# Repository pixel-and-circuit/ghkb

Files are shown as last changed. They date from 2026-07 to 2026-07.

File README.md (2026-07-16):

GHKB

<picture>
  <source media="(prefers-color-scheme: dark)" srcset="docs/images/case-preview-dark.png">
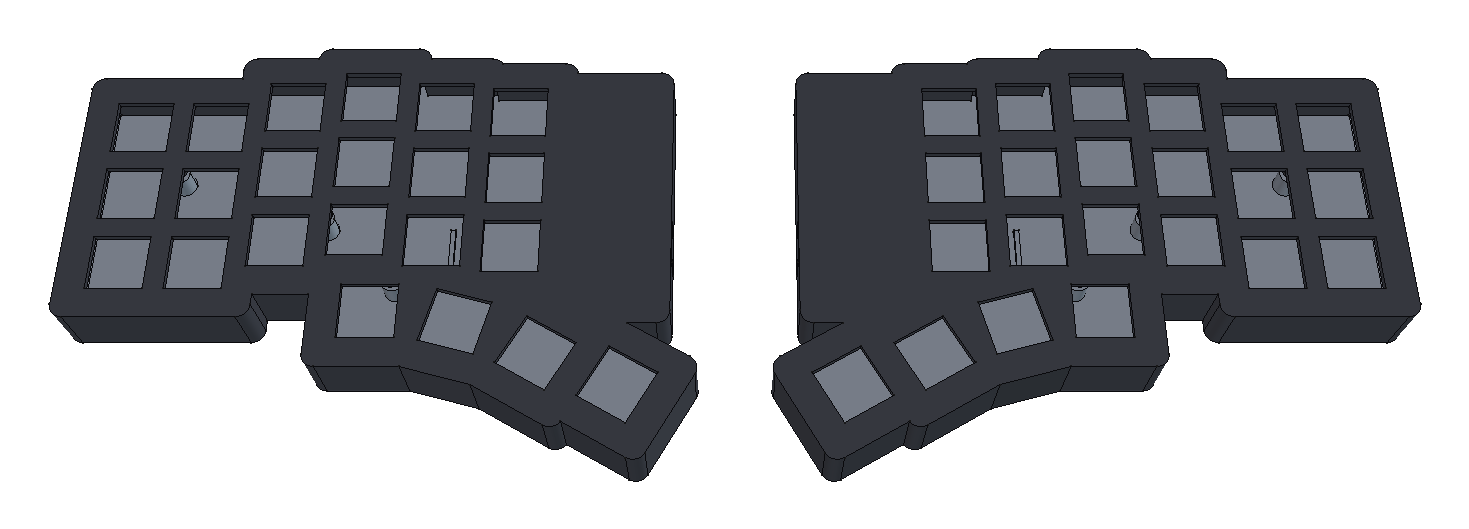
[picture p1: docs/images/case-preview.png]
GHKB split keyboard case, FreeCAD preview render of both halves
  
</picture>

GHKB is an open-source split mechanical keyboard project focused on custom hardware, modern firmware, and long-term experimentation.

The goal of this project is to build a fully custom wireless split keyboard from the ground up, including both the hardware and firmware stack. Rather than assembling an existing design, GHKB documents the complete engineering process—from PCB and enclosure design to firmware development.

Goals

Phase 1: Build a Reliable Daily Driver

Develop a fully functional wireless split keyboard featuring:

* Custom PCB designed with KiCad (single reversible design shared by both halves)
* Custom 3D-printed enclosure
* MX-compatible mechanical switches on hotswap sockets
* Battery-powered operation
* Bluetooth Low Energy (BLE)
* ZMK firmware
* Comfortable ergonomic layout

Controller strategy: the first prototype targets an off-the-shelf nRF52840
controller module (e.g. Nice!Nano) socketed onto the PCB. Designing a fully
custom controller—placing the nRF52840 QFN/BGA package directly on the board—is
a later, optional goal once the socketed design is validated.

Hardware design decisions:

* Layout: 42 keys — a 3x6 column-staggered matrix plus a 3-key thumb cluster
  per half (Corne-style), with an optional EC11 rotary encoder position.
* PCB: one reversible PCB serves both halves (components mount on the front
  for one half and on the back for the other), halving design and
  manufacturing effort.
* Switches: MX hotswap sockets (Kailh), so the prototype can be reworked
  without desoldering.
* Display: none. A display only shows status (battery, layer, BLE profile)
  and is not needed for keyboard operation; omitting it saves cost, battery,
  and three GPIOs kept as spares.
* RGB: deferred past Phase 1. Per-key RGB is battery-hostile on a wireless
  board; at most, unpopulated footprints are reserved.
* Layout generation: switch placement and the board outline are generated
  with ergogen and imported into KiCad, so layout iterations stay
  reproducible.

Phase 2: Develop a TinyGo Firmware

Create a native TinyGo firmware targeting the same hardware platform. The
long-term objective is not simply to recreate existing keyboard firmware, but to
explore whether a modern Go-based embedded ecosystem can become a practical
alternative for custom keyboard development.

Because the wireless BLE stack is by far the highest-risk part of this effort,
Phase 2 is split into two independent milestones:

Phase 2a: USB-wired TinyGo firmware (high feasibility)

Bring up a wired, single-board or wired-split TinyGo build using USB HID, which
is well supported in the TinyGo ecosystem and has existing precedent. This
establishes the matrix scanning, keymap, and feature layer in Go without
depending on wireless.

Phase 2b: BLE-wireless TinyGo firmware (research / uncertain)

Extend the firmware to full wireless operation. This is genuinely exploratory
and may not be achievable: TinyGo's BLE support (`tinygo.org/x/bluetooth`) has
historically centered on the central/scanner role and relies on Nordic's
SoftDevice, whereas a keyboard needs a BLE peripheral with HID-over-GATT,
pairing/bonding, and a wireless split link. ZMK gets these for free from
Zephyr's mature BLE stack; in TinyGo much of it would have to be built from
scratch. Treat Phase 2b as an open question, not a scheduled deliverable.

Planned Features

* Wireless split architecture
* Bluetooth Low Energy (BLE)
* Multi-device pairing
* Battery management
* USB-C charging
* Layer support
* Mod-Tap / Hold-Tap
* Combo keys
* Rotary encoder support
* Optional RGB lighting (post-Phase 1)
* Firmware updates via bootloader

Repository Structure

Note: this is the planned/target layout for the completed project. The
repository currently contains only this README while the project is in the
planning and hardware design phase; directories below are created as work
progresses.

```
.
├── README.md
├── HARDWARE.md
├── LICENSE
├── .gitignore
├── config/
│   ├── west.yml
│   ├── ghkb.keymap
│   └── boards/shields/ghkb/
├── build.yaml
├── firmware/
│   └── tinygo/
├── pcb/
│   ├── ergogen/
│   │   ├── config.yaml
│   │   └── footprints/
│   ├── keyboard.kicad_pro
│   ├── keyboard.kicad_sch
│   ├── keyboard.kicad_pcb
│   └── libraries/
├── case/
│   ├── source/
│   │   ├── params.py
│   │   ├── layout.py
│   │   ├── ghkb_case.py
│   │   ├── render_preview.py
│   │   ├── left.FCStd
│   │   └── right.FCStd
│   ├── exports/
│   │   ├── left.step / right.step
│   │   └── {left,right}_{top,bottom}.stl
│   └── reference/
│       └── keyboard_pcba.step
├── docs/
│   ├── assembly.md
│   ├── wiring.md
│   └── images/
│       └── case-preview{,-dark}.png
└── bom/
    └── bom.csv
```

Directory Overview

Directory	Description
HARDWARE.md	Sourcing guide: full parts table with purchase links, PCB fab options, and assembly cautions.
config	Production ZMK firmware config (west manifest, keymap, custom ghkb shield). Lives at the repo root because ZMK's reusable CI workflow expects config_path/build_matrix_path relative to the west topdir, which must be the repo root - not a nested subdirectory.
firmware/tinygo	Experimental TinyGo firmware implementation.
pcb	KiCad project files, schematics, PCB layout, and custom libraries.
pcb/ergogen	Ergogen layout source (YAML) and reversible footprint library.
case/source	Parametric enclosure build scripts (params/layout/ghkb_case.py) and the generated FreeCAD documents. The switch plate is integrated into the top shell, so there is no separate plate design. Rebuild everything with `freecadcmd case/source/ghkb_case.py`; the build asserts its geometry against the routed PCB and aborts on drift. `render_preview.py` regenerates the README preview images from the built FCStd documents (needs the FreeCAD GUI).
case/exports	Exported manufacturing files (per-half STEP, print-ready top/bottom STLs).
case/reference	kicad-cli STEP export of the routed PCB, used for interference checks.
docs	Assembly guide, wiring documentation, and project images.
bom	Bill of Materials used to build the keyboard.

Roadmap

* Finalize the keyboard layout (42-key, 3x6+3 per half)
* Design the PCB (single reversible board, ergogen + KiCad)
* Design the enclosure (integrated-plate top shell + screwed lid, parametric FreeCAD build; v1 done, pending print validation)
* Build the first prototype
* Bring up ZMK firmware
* Validate the hardware
* Use as a daily driver
* Develop USB-wired TinyGo firmware (Phase 2a)
* Investigate BLE-wireless TinyGo firmware (Phase 2b, research)
* Document the complete development process

Status

This project is currently in the planning and hardware design phase.

Contributing

Contributions are welcome.

Whether you are interested in mechanical keyboards, embedded systems, TinyGo, ZMK, PCB design, or 3D modeling, feel free to open an issue or submit a pull request.

License

This project is dual-licensed to ensure that anyone who uses, modifies, or sells
GHKB — commercially or otherwise — must release their own source under the same
copyleft terms.

- **Software / firmware / source code** (everything in `config/`, `zmk/`,
  `modules/`, `firmware/`, build scripts, documentation sources, etc.) is
  licensed under the **GNU General Public License v3.0 (GPL-3.0)** — a strong
  copyleft license. You may sell copies, but any distributed modified version
  must be released as source under GPL-3.0. See the `LICENSE` file.

- **Hardware designs** (`pcb/`, `case/`, including KiCad projects, schematics,
  PCB layouts, footprints, and 3D-printed enclosure source) are licensed under
  the **CERN Open Hardware Licence v2 – Strongly Reciprocal (CERN-OHL-S)**.
  Any product or design derived from these must have its corresponding design
  source made available under the same licence. See the `LICENSE-HARDWARE` file.

In short: **commercial sale is allowed, but reciprocity is mandatory** — if you
convey GHKB (or a derivative) to others, your modified software and hardware
source must stay open under these licenses.

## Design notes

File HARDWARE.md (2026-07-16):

# GHKB Hardware Sourcing

> **License note:** the hardware designs in this repository (`pcb/`, `case/`,
> KiCad projects, schematics, PCB layouts, footprints, and the 3D-printed
> enclosure source) are licensed under the **CERN Open Hardware Licence v2 –
> Strongly Reciprocal (CERN-OHL-S)**. You may manufacture and sell hardware
> based on these designs, but any product or derived design you convey to others
> must have its corresponding design source made available under CERN-OHL-S.
> See `LICENSE-HARDWARE`. (Software/firmware is separately licensed under
> GPL-3.0 — see `LICENSE`.)

조달용 부품 목록. 기준: `pcb/keyboard.kicad_pcb`(리버서블 1종)과
`case/source/params.py`의 v1 설계. 수량은 **양쪽 하프 합산 기준**이며,
소모품(다이오드/소켓/나사)은 여유분을 포함해 사는 것을 전제로 팩 단위
링크를 걸었다. 링크와 가격은 2026-07 조회 기준이라 품절 시 동일 검색어로
대체하면 된다.

부품별 정확한 대응 규격의 근거는 `pcb/ergogen/footprints/*.js` 헤더에
문서화되어 있다 (ceoloide 풋프린트가 명시하는 호환 부품).

## PCB 주문

| 항목 | 값 |
|---|---|
| 보드 | `pcb/keyboard.kicad_pcb` — 리버서블 1종, 좌/우 공용 |
| 외형 | 149.2 × 105.8 mm |
| 층수 / 두께 | 2층 / 1.6 mm |
| 표면처리 | HASL(무연)이면 충분, ENIG 선택사항 |
| 수량 | 2장 사용 (대부분 업체 최소 5장 — 여분은 자연 확보) |
| 특이사항 | M2.2 NPTH 6개 포함. `PWR1`(전원 스위치) 패드가 보드 엣지에 걸리는 것은 사이드 마운트 부품의 의도된 배치 (무넷 기계 패드) |

거버/드릴 파일은 발주 직전 `kicad-cli`로 생성한다 (업체별 프리셋 상이).

### 발주 서비스

| 서비스 | 비고 |
|---|---|
| [JLCPCB](https://jlcpcb.com/) | 해외(중국). 개인 개발자 사실상 표준 — 2층 5장 $2~ 수준, 한국 배송 1~2주. KiCad 거버 그대로 접수 |
| [PCBWay](https://www.pcbway.com/) | 해외(중국). JLCPCB와 양대 산맥, 품질/옵션 다양 |
| [한샘디지텍](https://www.hsdgt.com/) | 국내. 소량 시제작 대표 업체 — 빠른 납기, 한국어 응대 (해외 대비 가격 높음) |
| [샘플PCB](https://www.samplepcb.co.kr/) | 국내. 온라인 견적/발주 플랫폼 |

## 보드 실장 부품

| 부품 | 규격 / 부품번호 | 필요 수량 (구매 단위) | 링크 |
|---|---|---|---|
| 컨트롤러 | nice!nano v2 호환 (SuperMini nRF52840) | 2 | [AliExpress](https://www.aliexpress.com/item/1005009026511947.html) |
| 컨트롤러 소켓 (암) | 2.54mm 라운드홀 female 헤더, 12P×4줄 (40P 바 재단) | 4줄 (10줄 팩) | [AliExpress](https://www.aliexpress.com/item/32896689725.html) |
| 컨트롤러 핀 (수) | 2.54mm 금도금 라운드 수핀, 24핀/보드 | 48핀 (40P×10줄 팩) | [AliExpress](https://www.aliexpress.com/item/32219458766.html) |
| 핫스왑 소켓 | Kailh CPG151101S11 (MX) | 42 (70개 팩) | [AliExpress](https://www.aliexpress.com/item/1005012011087592.html) |
| 다이오드 | 1N4148, DO-35 THT (SOD-123 겸용 풋프린트) | 44 (50개 팩) | [AliExpress](https://www.aliexpress.com/item/1005007970187200.html) |
| 배터리 커넥터 | JST S2B-PH-K-S (PH 2.0mm, THT 사이드) | 2 (10개 팩) | [AliExpress](https://www.aliexpress.com/item/1005007176267255.html) |
| 배터리 | LiPo 301230, 3.7V ~110mAh, PH2.0 플러그, 보호회로 포함 | 2 | [AliExpress](https://www.aliexpress.com/item/1005005348368664.html) |
| 전원 스위치 | MSK-12C02 7핀 SMD 슬라이드 (Alps SSSS811101 호환) | 2 (50개 팩) | [AliExpress](https://www.aliexpress.com/item/4000685483225.html) |
| 리셋 스위치 | C&K PTS636 SM43 LFS (THT 상면 누름) | 2 (최소 5개) | [LCSC C2689636](https://www.lcsc.com/product-detail/C2689636.html) — 알리 미취급 |
| 로터리 엔코더 (옵션) | EC11, 푸시버튼 포함, 샤프트 15mm 권장 | 0~2 (5개 팩) | [AliExpress](https://www.aliexpress.com/item/1005008708996963.html) |

## 스위치 / 키캡

| 부품 | 규격 | 필요 수량 | 링크 |
|---|---|---|---|
| 키 스위치 | MX 호환 (예: Gateron Milky Yellow Pro, 5핀) | 42 (45개 팩) | [AliExpress](https://www.aliexpress.com/item/1005009861228283.html) |
| 키캡 | 1u × 42 (XDA/DSA blank PBT, Corne류 세트) | 1세트 | [AliExpress](https://www.aliexpress.com/item/1005008944545863.html) |
| 엔코더 노브 (옵션) | 6mm D/널링 샤프트용, 외경 ≤19mm | 0~2 | EC11 구매 시 함께 검색 |

## 케이스 하드웨어

케이스 자체는 구매가 아니라 출력: `case/exports/{left,right}_{top,bottom}.stl`
(PETG/PLA, 페리미터 4+, 인필 40%+, 쉘은 플레이트면·리드는 바깥면을 베드에).

| 부품 | 규격 | 필요 수량 (구매 단위) | 링크 |
|---|---|---|---|
| 히트셋 인서트 | M2, OD 3.2 × L 4.0 (구매 시 이 치수 선택 필수) | 10 (키트) | [AliExpress](https://www.aliexpress.com/item/1005007830491580.html) |
| 케이스 나사 | M2×14 접시머리 (DIN 965, 90°) | 10 (100개 팩) | [AliExpress](https://www.aliexpress.com/item/32367579698.html) |
| 범폰 | Ø8 × 2mm 실리콘, 자체접착 | ~12 (팩) | [AliExpress](https://www.aliexpress.com/item/1005006455782191.html) |

## 기타

- USB-C **데이터** 케이블 1개 (펌웨어 플래싱/충전용, 충전전용 케이블 불가)
- 납땜 인두 + 인서트 압입 팁 (인서트 키트에 팁 포함 옵션 있음)

## 조립 시 주의

- **TRRS 커넥터는 없다.** 완전 무선(BLE) 스플릿이라 보드에 풋프린트
  자체가 없다 — 유선 스플릿 BOM을 참고해 사지 말 것.
- **LiPo 극성**: JST-PH 배터리의 +/− 배선은 표준화되어 있지 않다.
  연결 전 보드 실크의 +/− 표기와 대조하고, 반대면 커넥터에서 핀을
  빼서 바꿔 끼운다. 극성 반대로 꽂으면 컨트롤러가 죽는다.
- **리버서블 보드**: 같은 PCB 2장에서 오른쪽은 앞면(F, "R hand back
  side" 실크 기준), 왼쪽은 뒷면(B)에 부품을 실장한다. 하프당 실장면이
  다를 뿐 부품은 동일.
- 컨트롤러는 직납하지 않고 소켓 실장한다 (라운드홀 암 헤더를 PCB에,
  수핀을 나노에). 클론 보드에 동봉되는 사각핀 헤더는 라운드 소켓과
  마모 궁합이 나빠 쓰지 않는다.

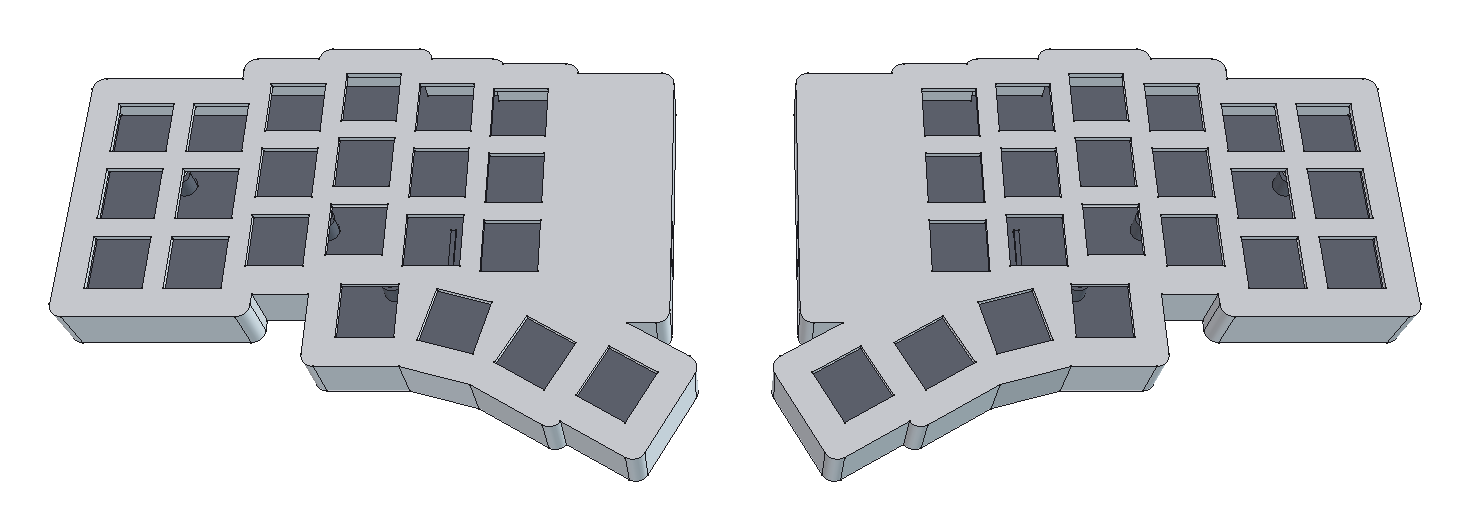
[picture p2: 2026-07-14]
docs/images/case-preview-dark.png

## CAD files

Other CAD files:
case/exports/left.step
case/reference/keyboard_pcba.step
case/exports/right_bottom.stl
case/exports/right_top.stl
case/exports/right.step
case/exports/left_top.stl
case/exports/left_bottom.stl
case/source/left.FCStd
case/source/right.FCStd

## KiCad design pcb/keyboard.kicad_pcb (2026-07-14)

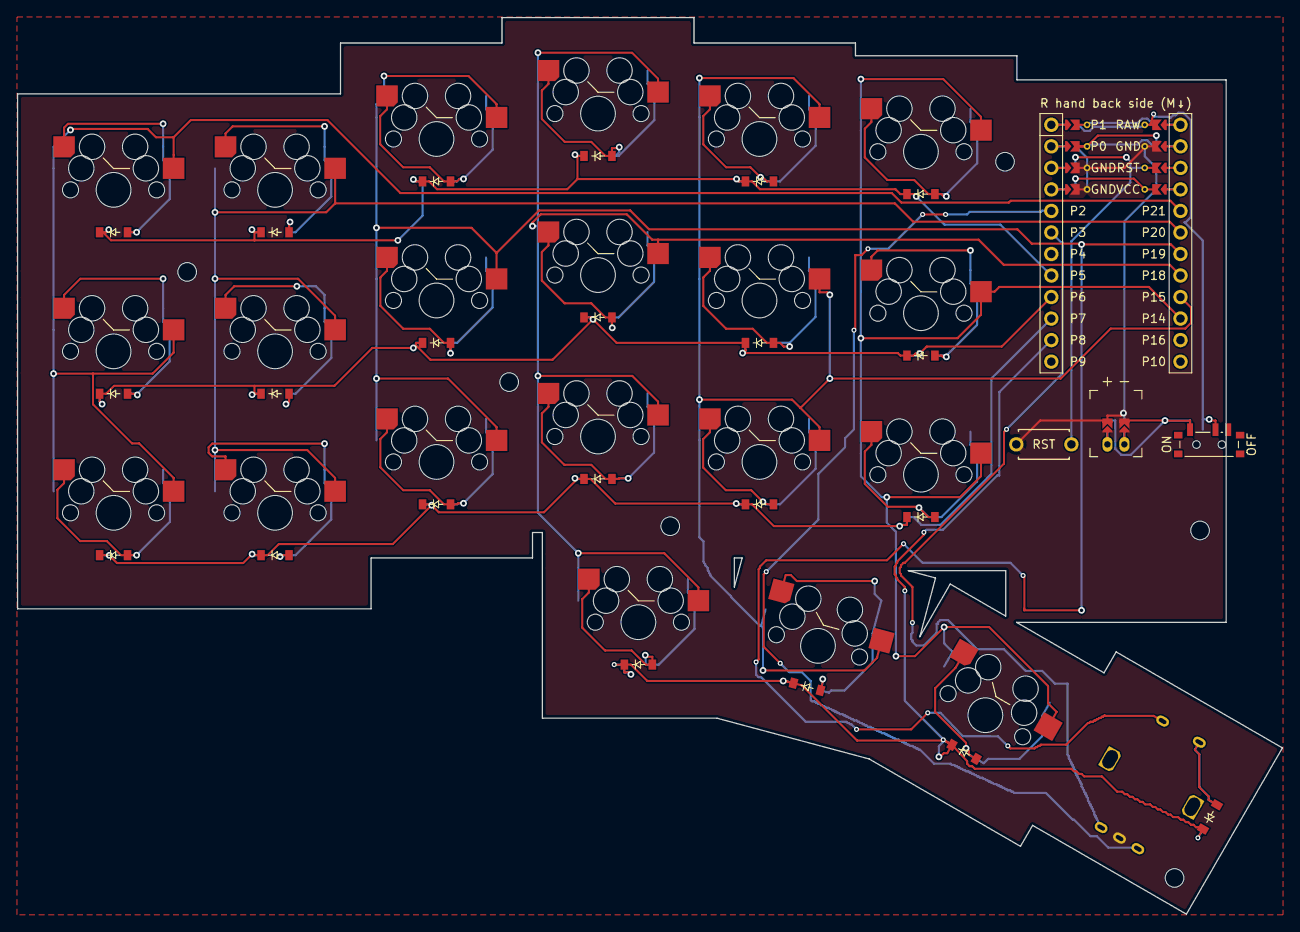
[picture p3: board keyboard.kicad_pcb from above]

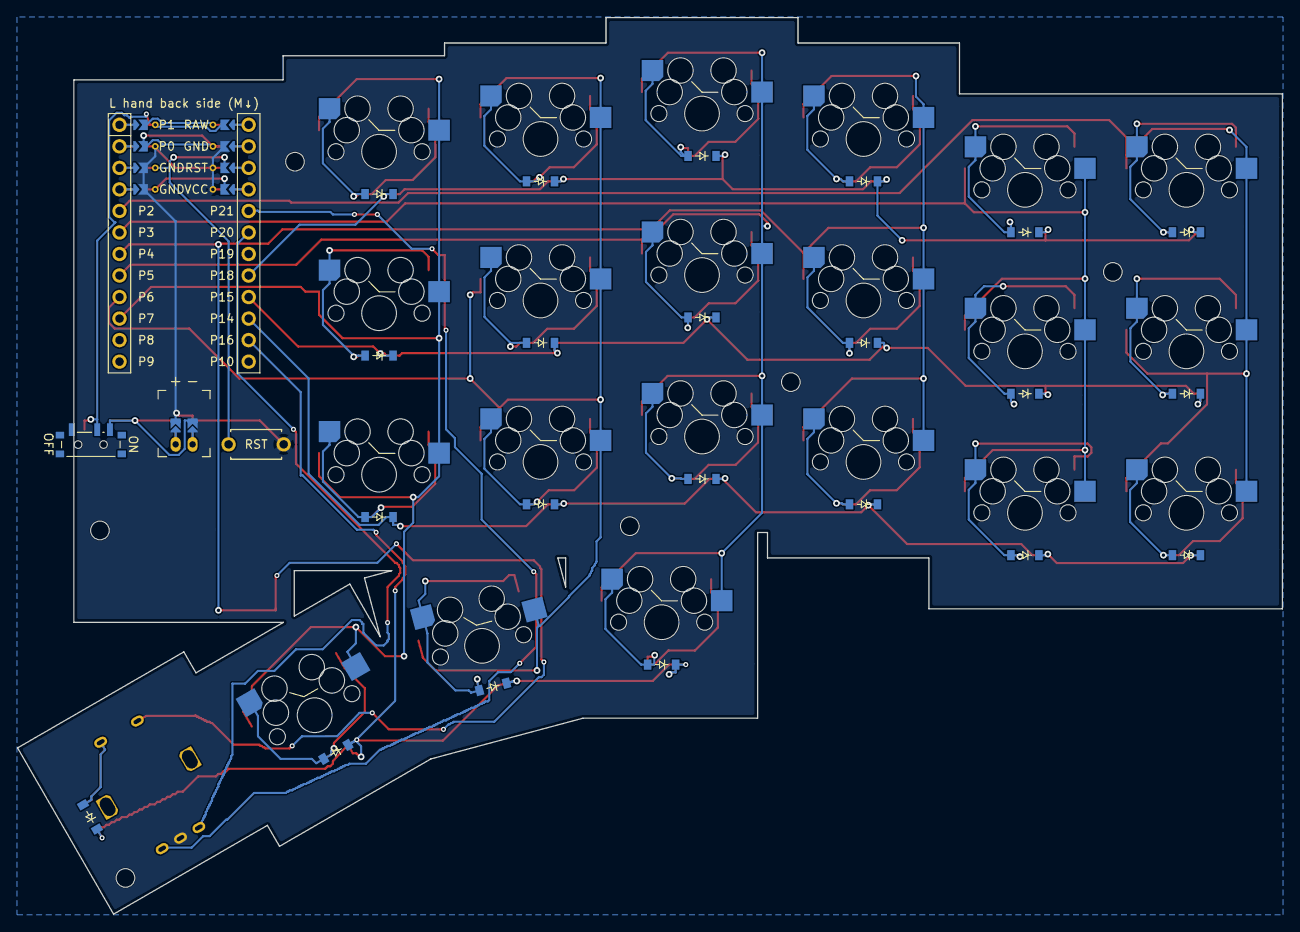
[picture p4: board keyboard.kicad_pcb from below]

Board: 2 copper layers, 149.2 x 105.8 mm, 54 parts (21 on the bottom side), 40 nets.

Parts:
D1, D2, D3, D4, D5, D6, D7, D8, D9, D10, D11, D12, D13, D14, D15, D16, D17, D18, D19, D20, D21, D22: diode_tht_sod123
JST1: battery_connector_jst_ph_2
MCU1: mcu_nice_nano
MH1, MH2, MH3, MH4, MH5, MH6: MountingHole_2.2mm
PWR1: power_switch_smd_side
RE1: rotary_encoder_ec11_ec12
RST1: reset_switch_tht_top
S1, S2, S3, S4, S5, S6, S7, S8, S9, S10, S11, S12, S13, S14, S15, S16, S17, S18, S19, S20, S21: switch_mx

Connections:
BAT_P: JST1.1, PWR1.1, PWR1.3
GND: JST1.2, MCU1.102, MCU1.121, MCU1.122, RE1.B, RST1.2
JST1_1: JST1.11, JST1.21, JST1.31
JST1_2: JST1.12, JST1.22, JST1.32
P2: MCU1.20, RE1.A
P3: MCU1.19, RE1.C
P5: D3.1, D6.1, D9.1, D12.1, D15.1, D18.1, MCU1.17
P6: D2.1, D5.1, D8.1, D11.1, D14.1, D17.1, MCU1.16
P7: D1.1, D4.1, D7.1, D10.1, D13.1, D16.1, MCU1.15
P8: D19.1, D20.1, D21.1, D22.1, MCU1.14
P14: MCU1.10, S16.1, S17.1, S18.1, S21.1
P15: MCU1.9, S13.1, S14.1, S15.1, S20.1
P18: MCU1.8, S10.1, S11.1, S12.1, S19.1
P19: MCU1.7, RE1.S1, S7.1, S8.1, S9.1
P20: MCU1.6, S4.1, S5.1, S6.1
P21: MCU1.5, S1.1, S2.1, S3.1
RAW: MCU1.101, PWR1.2
RST: MCU1.103, RST1.1
enc: D22.2, RE1.S2
far_thumb: D21.2, S21.2
home_thumb: D20.2, S20.2
index_bottom: D13.2, S13.2
index_home: D14.2, S14.2
index_top: D15.2, S15.2
inner_bottom: D16.2, S16.2
inner_home: D17.2, S17.2
inner_top: D18.2, S18.2
middle_bottom: D10.2, S10.2
middle_home: D11.2, S11.2
middle_top: D12.2, S12.2
near_thumb: D19.2, S19.2
outer_bottom: D1.2, S1.2
outer_home: D2.2, S2.2
outer_top: D3.2, S3.2
pinky_bottom: D4.2, S4.2
pinky_home: D5.2, S5.2
pinky_top: D6.2, S6.2
ring_bottom: D7.2, S7.2
ring_home: D8.2, S8.2
ring_top: D9.2, S9.2

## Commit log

2026-07-12 chore: add gitignore and git LFS attributes
    Track 3D/CAD/image binaries via LFS; ignore KiCad backups,
    ergogen output, firmware build artifacts.
2026-07-12 docs: record hardware design decisions in README
    42-key (3x6+3) reversible single PCB, MX hotswap, no display
    (status-only, battery-hostile), RGB deferred, ergogen pipeline.
2026-07-12 feat(pcb): fully routed reversible split keyboard PCB
    ergogen layout source (42 keys + dedicated EC11 position) with
    vendored ceoloide reversible footprints (MIT), generated and fully
    routed KiCad 10 board: Freerouting for the bulk, custom grid A*
    router for the rest, GND pours both sides.
    Encoder A/C on P2/P3 (P0.17/P0.20); P0/P1 jumper block too
    congested to route out. DRC: 0 unconnected, 0 violations except
    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
    [keyboard.kicad_pcb]
2026-07-12 build(zmk): scaffold ZMK west workspace and CI build matrix
    Adds the west manifest, GitHub Actions build matrix, and reusable
    build-user-config.yml workflow wiring for the ghkb ZMK firmware,
    pointed at firmware/zmk/{config,build.yaml} for this monorepo layout.
    No shield exists yet (GYE-269), so the build matrix is expected to
    fail until then.
    Also widens .gitignore to a whitelist under firmware/zmk/, since
    `west update` materializes module directories there whose exact set
    varies by manifest group (zephyr/, modules/, optional/, etc.) rather
    than a fixed, enumerable list.
2026-07-12 feat(zmk): add ghkb shield scaffolding
    Adds boards/shields/ghkb/ Kconfig.shield, Kconfig.defconfig,
    ghkb.zmk.yml metadata, and empty per-side .conf placeholders for the
    ghkb_left / ghkb_right shields.
    Also fixes two issues found while build-verifying this against the
    real ZMK toolchain (zmkfirmware/zmk-build-arm:stable, local docker):
    - build.yaml referenced board `nice_nano_v2`, which no longer exists
    under Zephyr's hardware model v2 - it's just `nice_nano` now, whose
    default_revision is already "2.0.0" (what nice_nano_v2 used to mean).
    - west.yml pins the zmk revision to the exact commit validated here,
    since current main prints a deprecation warning on the
    config/boards/shields/<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
2026-07-12 feat(zmk): define GPIO matrix kscan wiring for ghkb
    Adds ghkb.dtsi (shared kscan0: col2row, 4 rows P5/P6/P7/P8) and
    per-side col-gpios in ghkb_left.overlay / ghkb_right.overlay (left:
    P21,P20,P19,P18,P15,P14; right: reversed), matching
    pcb/ergogen/config.yaml's net names.
    Build verified against zmkfirmware/zmk-build-arm:stable:
    - ghkb_right (peripheral) builds all the way to a working zephyr.uf2
    already at this stage - peripherals don't compile keymap.c
    (CMakeLists.txt gates it behind SPLIT_ROLE_CENTRAL), so no keymap
    is needed for them to be feature-complete.
    - ghkb_left (central) proceeds through real compilation and stops at
    the expected "Keymap node not found" boundary (GYE-274)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
2026-07-12 feat(zmk): add 42-key + encoder physical layout and matrix transform
    Adds zmk,physical-layout + default_transform (12 cols x 4 rows, 44
    RC() entries) to ghkb.dtsi, and col-offset=<6> to ghkb_right.overlay
    so the shared transform mirrors correctly for the reversed-wiring
    right shield (matches zmkfirmware/zmk's jorne_right.overlay pattern).
    Row-3 (thumb + encoder) ordering fix found during review: thumb/
    encoder RC() column values are borrowed from main-matrix column nets
    (near=P18/middle, home=P15/index, far=P14/inner, encoder=P19/ring),
    so listing them in ascending electrical order does not match true
    physical left-to-right position the way it does for the main matrix.
    Recomputed the true o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
2026-07-12 feat(zmk): add EC11 encoder sensor and pushbutton wiring
    Adds encoder0 (alps,ec11, A=P2/C=P3 direct GPIOs, 80 steps) and the
    zmk,keymap-sensors sensors node to ghkb.dtsi. No chosen entry needed
    for zmk,keymap-sensors - picked up automatically. sensor-bindings
    (actual rotation behavior) is deferred to GYE-274's keymap.
    Build verified: EC11 driver (ec11.c) compiles and links cleanly for
    both shields (confirmed via ghkb_right's full build); ghkb_left
    reaches the same expected "Keymap node not found" boundary as prior
    tasks, with zero devicetree-stage errors.
2026-07-12 feat(zmk): enable dual-battery reporting for split ghkb halves
    Adds CONFIG_ZMK_SPLIT_BLE_CENTRAL_BATTERY_LEVEL_FETCHING/PROXY to
    ghkb_left.conf so both halves' independent JST-PH batteries get
    reported to the host, not just the central's (ZMK default). Symbol
    names verified against zmk/app/src/split/bluetooth/Kconfig.
    Also fixes a much bigger issue found while build-verifying this:
    neither CONFIG_ZMK_BLE nor CONFIG_ZMK_USB were actually resolving to
    'y' in the final .config, despite nice_nano's own board defconfig
    setting both - meaning ble.c/hog.c were silently excluded from the
    build and the keyboard would have had no way to talk to a host at
    all. Reproduced identically with ZMK's own unm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
2026-07-12 feat(zmk): add base/nav keymap layers and encoder bindings
    Adds ghkb.keymap (no _left/_right suffix - shared by both shields,
    matching corne/jorne convention):
    - default_layer: QWERTY, 4 home-row mods (D/F/J/K via a shared
    zmk,behavior-hold-tap), thumb cluster (GUI/layer-mo/space/mute
    per side), encoder = volume on rotation.
    - nav_sym_layer: numbers/symbols + arrow keys/paging, encoder =
    page up/down on rotation.
    - One combo (S+D -> ESC) at keymap positions 14/15.
    Both layers have exactly 44 bindings (verified with a small regex
    count script), matching ghkb.dtsi's default_transform map order
    position-for-position (row0-2 outer..inner/inner..outer, row3
    near/home/far/[enc] per side).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
2026-07-13 fix(ci): add required //zmk board variant qualifier
    ZMK's Zephyr 4.1 (HWMv2) migration requires board IDs to explicitly
    include the "zmk" variant qualifier (nice_nano -> nice_nano//zmk);
    omitting it resolves to the stock board and silently builds without
    CONFIG_ZMK_BOARD_COMPAT=y, which the reusable CI workflow explicitly
    checks for and fails on ("The selected board is not set up for ZMK
    and there is a ZMK variant available") - confirmed via an actual
    GitHub Actions run.
    Verified locally: CONFIG_ZMK_BOARD_COMPAT=y now present in the
    resolved .config, build still succeeds (468992 bytes, up slightly
    from 449536 - the zmk variant's defconfig enables a bit more by
    default).
2026-07-13 feat(pcb): add M2 case mounting holes and clean autoroute artifacts
    Place six MountingHole_2.2mm NPTH footprints (MH1-MH6) for the 3D-printed
    case: top-shell posts seat on the PCB and lid towers clamp it from below.
    Positions verified against the routed board so the 2.2mm drill clears all
    copper by >=1.85mm, the post seat avoids solder joints, and the under-PCB
    tower corridor avoids hotswap sockets, the nice!nano, JST, and the battery
    pocket. Perimeter spots on the west side are fully occupied by column/row
    interconnects, so two holes sit at interior four-key corners instead.
    Clean up freerouting artifacts: remove two coincident duplicate vias on P3,
    rewrite the RAW branch near the nano wit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
    [keyboard.kicad_pcb]
2026-07-13 feat(case): scaffold parametric case sources with board-asserted layout
    case/source/layout.py recomputes every key/feature anchor from the ergogen
    parameters (stagger, cumulative thumb splay, encoder, MCU zone) in pure
    Python and asserts all 48 footprints, 6 mounting holes, and the outline
    bounding box against the routed pcb/keyboard.kicad_pcb at import time, so
    geometry drift fails the case build loudly. Verified under both python3
    and freecadcmd (ASCII-only source, explicit UTF-8 board read).
    case/source/params.py holds the case parameter set and the derived
    vertical stack (plate 1.5 / plate-to-pcb 5.0 / pcb 1.6 / under-pcb 6.5 /
    lid 2.4). case/reference/keyboard_pcba.step is the kicad-cl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
    [keyboard_pcba.step]
2026-07-13 feat(case): parametric shell+lid builder for both halves
    ghkb_case.py builds the integrated top shell (1.5mm plate, 14mm switch
    cutouts, EC11 pass-through, USB/power openings) and the bottom lid
    (clamp towers, battery ribs, countersunk M2 holes, reset access, bumpon
    recesses) for the left half, then rebuilds the right half from mirrored
    inputs -- solids are never mirrored, so STL normals stay valid.
    The board outline is unioned from the same padded tiles ergogen uses
    (outer wire only; the PCB's two interior holes stay covered), offset via
    arc joins for the cavity, wall, rebate, and lid profiles. Mount posts and
    towers are placed on the PCB mounting holes read from the routed board;
    holes wh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
2026-07-13 feat(case): generated FCStd documents and STEP/STL exports
    Build artifacts from freecadcmd case/source/ghkb_case.py at the current
    parameter set: per-half FCStd (top_shell + bottom_lid), assembly STEP,
    and print-ready STLs (watertight, volume within 0.05% of the BREP).
    All tracked via git LFS.
    [left.FCStd, left.step, left_bottom.stl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]
2026-07-13 docs: sync README tree/roadmap with the built case, fix half-side note
    The enclosure is now a parametric FreeCAD build with the switch plate
    integrated into the top shell, so the planned separate plate/ directory
    is gone and case/ gains the build scripts plus a reference/ dir for the
    interference-check STEP. Correct the ergogen meta note on which PCB face
    serves which half: the F-side silkscreen reads "R hand back side", so
    front-populated boards are the right half, not the left. Dedupe the
    kicad_prl ignore pattern.
2026-07-14 docs(case): render FreeCAD case previews into the README
    - case/source/render_preview.py composes left/right FCStd into a split
    pair and renders light/dark PNGs via the GUI (freecad-mcp runnable)
    - README gets a <picture> hero that follows GitHub's color scheme
    - docs/images/** kept out of LFS so README views don't burn LFS
    bandwidth quota (and render in LFS-less clones)
2026-07-16 docs(hardware): add parts sourcing guide
    - full parts table (board components, switches/keycaps, case hardware)
    with AliExpress/LCSC links checked against the ceoloide footprint
    specs (SSSS811101/MSK-12C02, PTS636SM43LFS, S2B-PH-K-S, CPG151101S11)
    - PCB order specs and fab options: JLCPCB/PCBWay + domestic
    Hansaem Digitec/SamplePCB
    - assembly cautions: no TRRS, LiPo polarity, reversible mounting,
    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
2026-07-16 feat(license): apply dual strong-copyleft licensing (GPL-3.0 + CERN-OHL-S)
    Switch from MIT to a dual copyleft model that permits commercial sale
    but forces reciprocity: anyone who conveys GHKB or a derivative must
    release their modified source under the same terms.
    - LICENSE: GPL-3.0 (full text) for all software/firmware/source
    - LICENSE-HARDWARE: CERN-OHL-S v2 (full text) for hardware designs
    - Update README.md and HARDWARE.md with dual-license explainer
    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
